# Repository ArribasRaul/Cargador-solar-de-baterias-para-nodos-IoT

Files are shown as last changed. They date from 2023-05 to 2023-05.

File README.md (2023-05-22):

# Cargador solar de baterias para nodos IoT

Diseño y desarrollo de un sistema que permita gestionar la energía generada por paneles solares de baja potencia de hasta 14 V y 3A . El sistema empleará una PCB que alimentará una batería de litio de 3,7V y una carga variable que consuma 3,3V o 5V y hasta 2A.
Proyecto de fin de grado realizado en la UPNa por Raúl Arribas Antón y supervisado por el Dr. Santiago Tainta Ausejo.

Universidad Publica de Navarra

##  [1. Códigos](https://github.com/ArribasRaul/Cargador-solar-de-baterias-para-nodos-IoT/tree/main/1.%20Codigos "Heading link")

Repositorio de los códigos utilizados durante el proyecto.

- Lectura_BQ25895

Codigo para la lectura de los registros del BQ25895 y escritura de estos en el monitor serie (Arduino Uno o Atmega328P)

- MPPT

Código para la implementación de un controlador MPPT (Arduino Uno o Atmega328P)
 
- Sistema_de_medida

Código y montaje para un sistema de medión de la eficiencia de un sistema de carga de baterias, basado en el INA3221, Arduino Uno y un modulo de microSD.

##  [2. PCB](https://github.com/ArribasRaul/Cargador-solar-de-baterias-para-nodos-IoT/tree/main/2.%20PCB "Heading link")

- Gerbers

Diseño de la PCB del cargador

- Lista de componentes de la PCB

Lista de los componentes usados en la PCB, sus referencias, cantidades y referencias de compra.

- Controlador

Comparación de los diferentes controladores de carga en el mercado.

- Regulador 3,3 V

Comparación de los diferentes convertidores DC/DC de 3,3 V en el mercado.

- Regulador 5 V

Comparación de los diferentes convertidores DC/DC de 5 V en el mercado.

##  [3. Pruebas PCB](https://github.com/ArribasRaul/Cargador-solar-de-baterias-para-nodos-IoT/tree/main/3.%20Pruebas%20PCB "Heading link")

- Lecturas

Datos en bruto conseguidos con el sistema de medida

- Comparación DFRobot y Desarollada

Comparación de funcionamiento de una PCB comercial (Solar Power Manager for 9V/12V/18V solar panel) de la marca DFRobot y la PCB desarrollada en diferentes situaciones de uso, conectadas a una fuente de alimentación.

- DFRobot

Funcionamiento de la placa de DFRobot con una alimentacion de dos paneles solares de baja potencia (9 V y 400 mA)

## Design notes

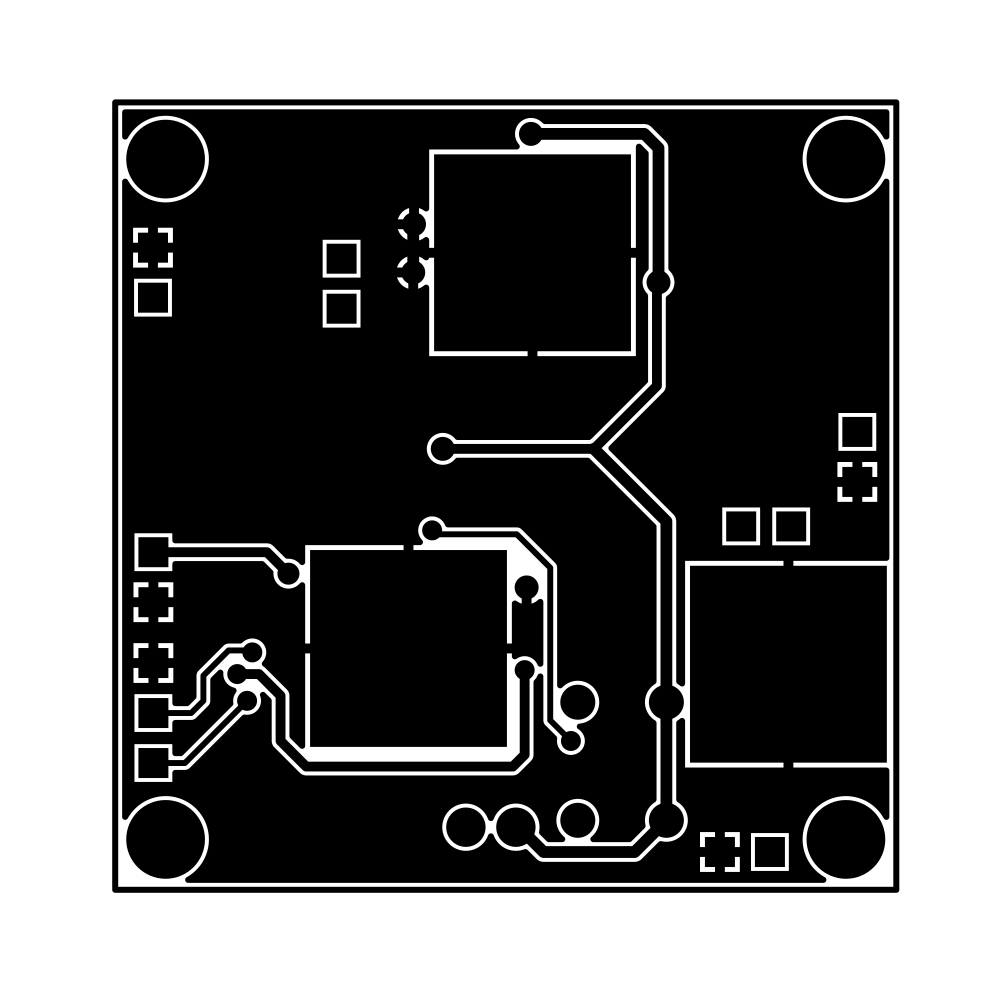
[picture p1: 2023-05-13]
2. PCB/Fotos PCB/4. Botton copper.png

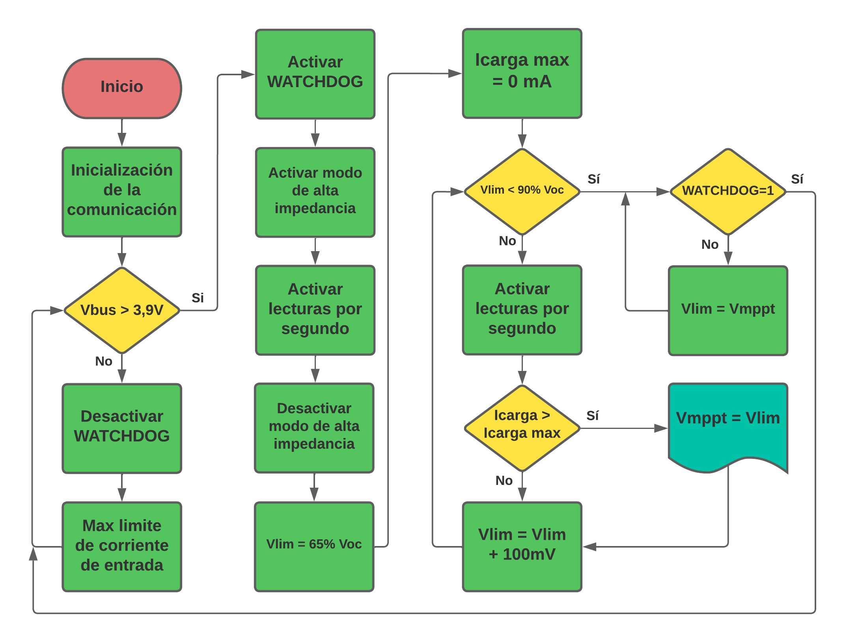
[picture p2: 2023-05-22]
1. Codigos/MPPT/Diagrama MPPT.png

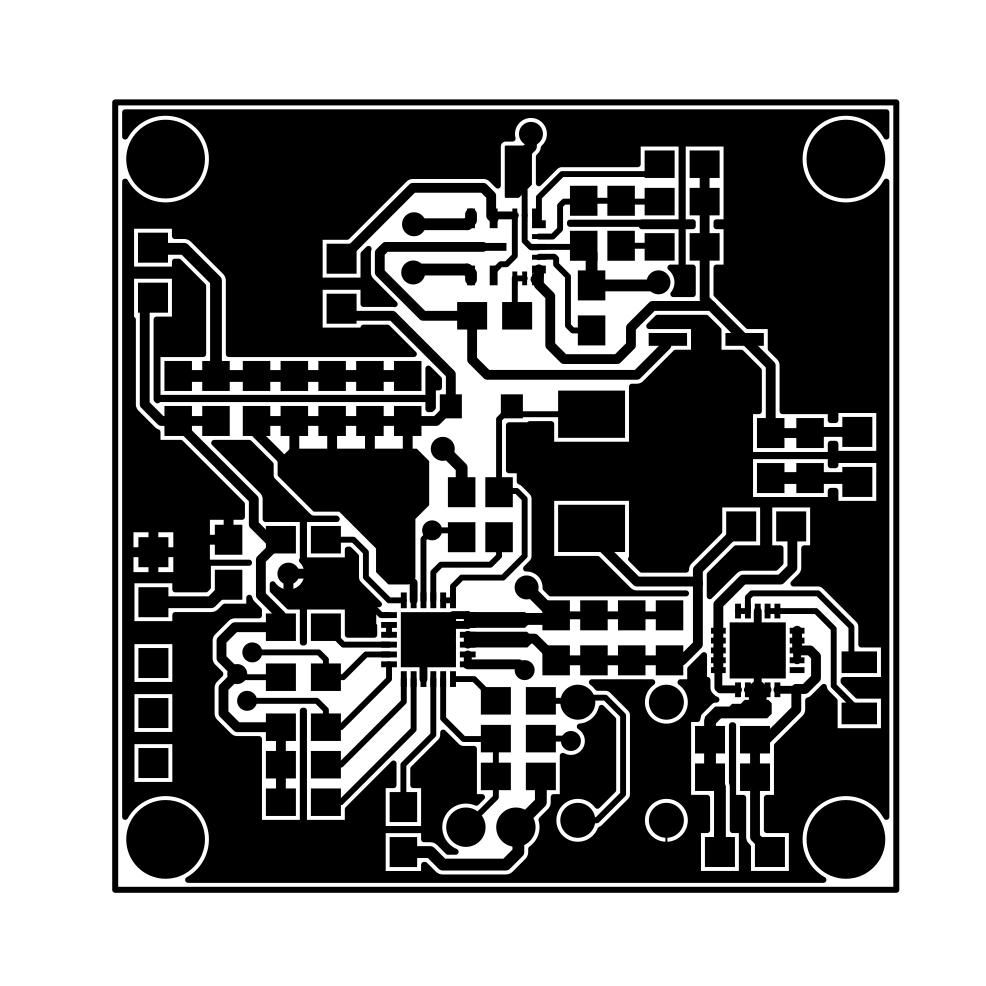
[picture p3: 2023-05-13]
2. PCB/Fotos PCB/3. Top copper.png

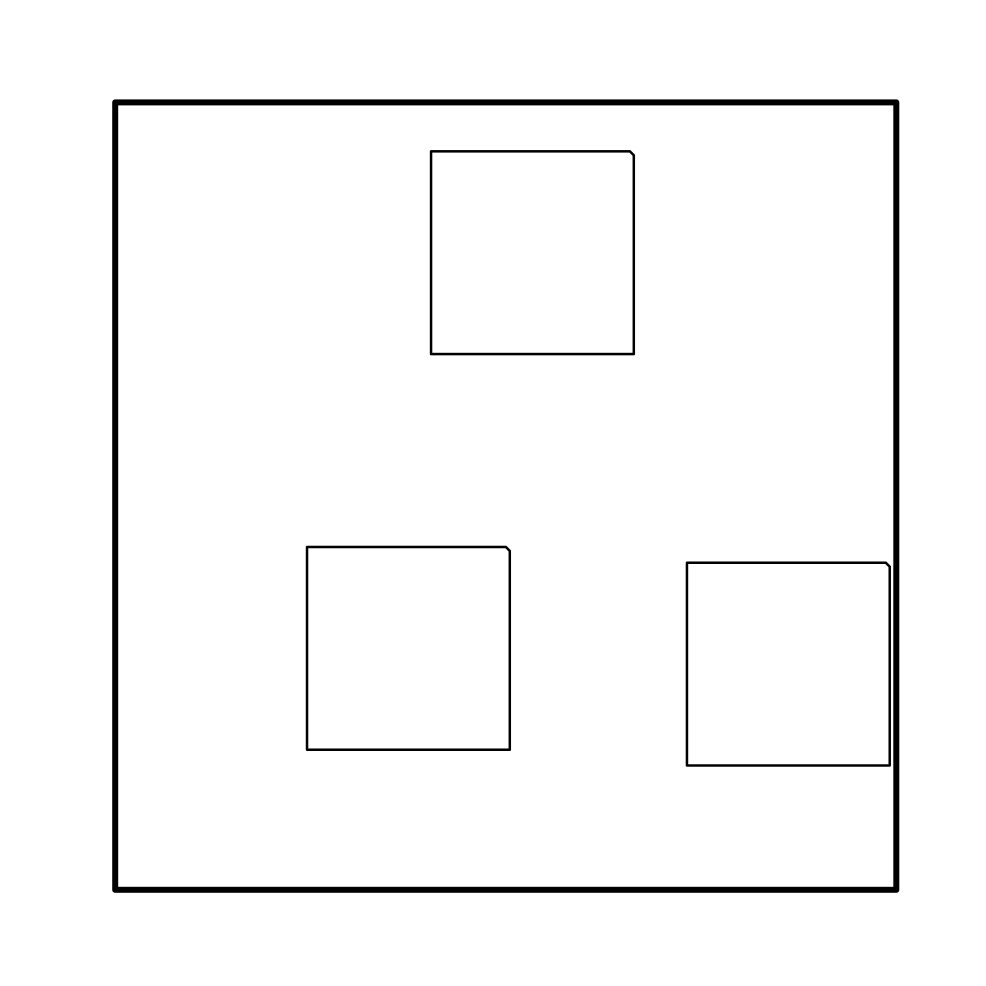
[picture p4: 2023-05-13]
2. PCB/Fotos PCB/6. Botton silckscreen.png

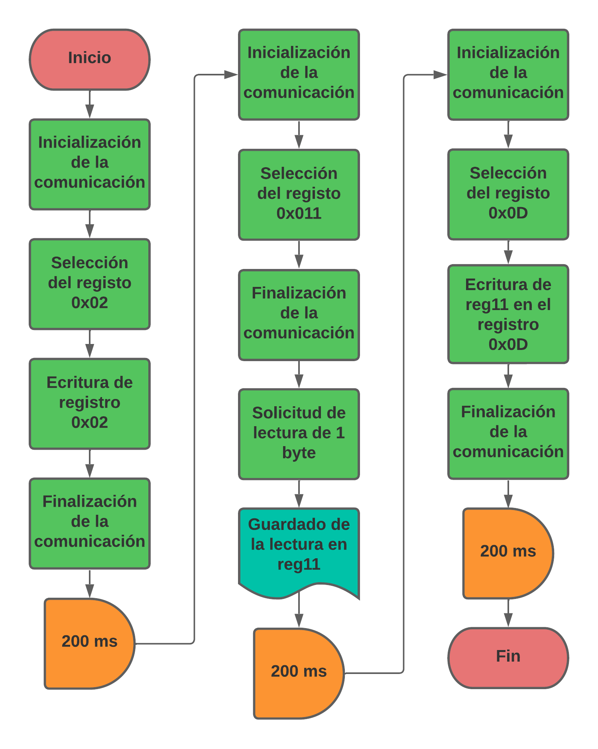
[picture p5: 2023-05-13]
1. Codigos/MPPT/Diagrama de flujo MPPT.png

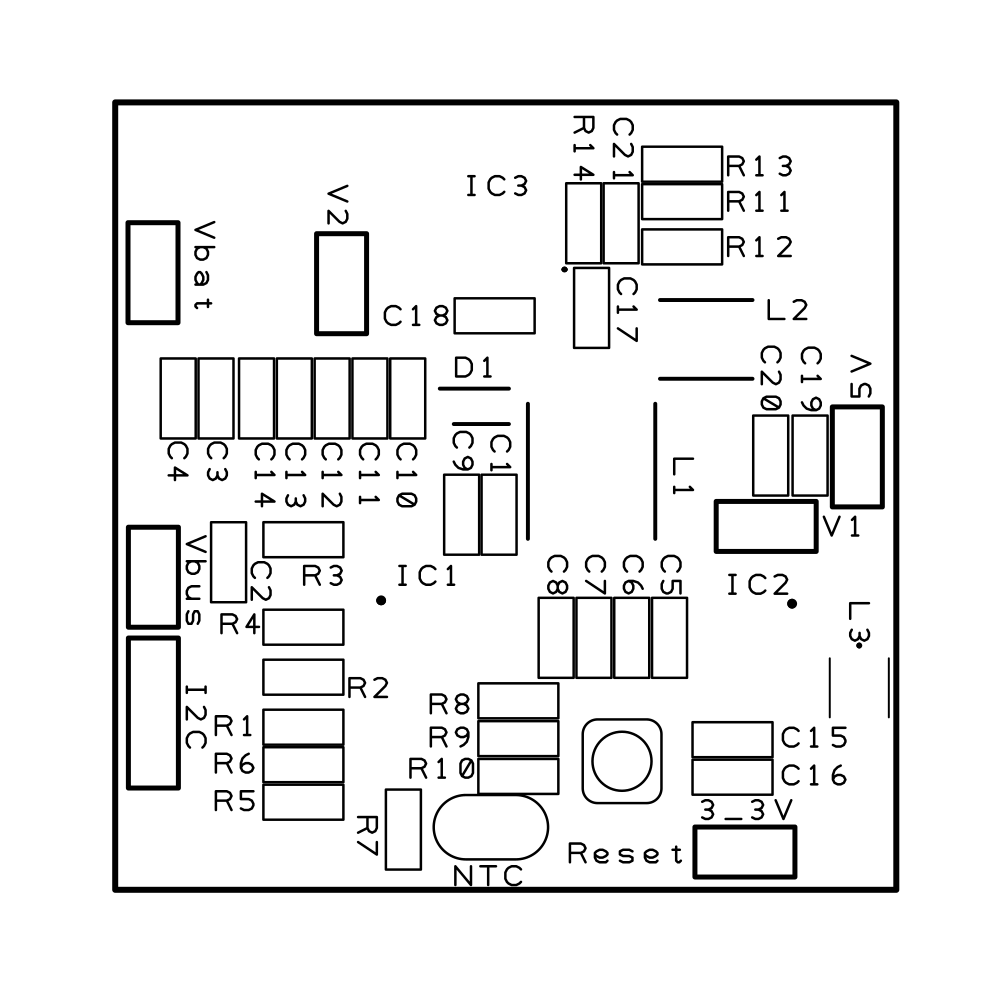
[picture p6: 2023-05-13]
2. PCB/Fotos PCB/1. Top silckscreen.png

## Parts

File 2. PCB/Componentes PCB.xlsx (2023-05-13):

Nombre | Cantidad | Valores | Decripción | Formato | Codigo RS | Mouser REF
R1/R2/R3/R4/R5/R6/R8 | 7 | 10k |  | 1206 | 788-3981 | 791-RMC1/8-1002FTP
R7 | 1 | 180 |  | 1206 | 721-9762 | 791-WR12X1800FTL
R9 | 1 | 5,23k |  | 1206 | - | 652-CR1206FX-5231ELF
R10 | 1 | 30,1k |  | 1206 | 243-0531 | 652-CR1206FX-3012ELF
R11/R13 | 2 | 100k |  | 1206 | 721-9986 | 603-RC1206JR-07100KL
R12 | 1 | 1k |  | 1206 | 721-9829 | 791-RMC1/8K1001FTP
R14 | 1 | 24,9k |  | 1206 | 252-7591 | 791-RMC1/8K2492FTP
C1 | 1 | 47n |  | 1206 | 250-7701 | 791-1206B473K500CT
C2/C17 | 2 | 1u |  | 1206 | 242-7428 | 187-CL31B105KBHNFNE
C3/C4/C5/C6/C7/C8/ C10/C11/C12/C13/C14 | 11 | 10u |  | 1206 | 260-8829 | 187-CL31A106MAHNNNE
C9 | 1 | 4,7u |  | 1206 | 247-8164 | 187-CL31B475KAHNNNE
C15/C16/C19/C20 | 4 | 22u |  | 1206 | 247-8160 | 187-CL31A226MOCLNNC
C18 | 1 | 100n |  | 1206 | 669-8417 | 791-SH21B104K160CT
C21 | 1 | 22p |  | 1206 | 669-8482 | 791-0805N220K201CT
D1 | 1 | 20V 1A | Diodo Schottky | SOD-123W | 151-3223 | 771-PMEG2010BER115
L1 | 1 | 2,2u |  | 2525 | - | 70-IHLP2525CZER2R2M1
L2 | 1 | 1,5u |  | - | - | 652-SRP4012TA-1R5M
L3 | 1 | 1u |  | - | - | 810-SPM3012T-1R0M
IC1 | 1 | - | BQ25895MRTWT | - | - | 595-BQ25895RTWR
IC2 | 1 | - | ISL91110IRNZ-T7A | - | - | 968-ISL91110IRNZ-T7A
IC3 | 1 | - | LMQ62440CPPQRJRRQ1 | - | - | 595-Q62440CPPQRJRRQ1
NTC | 1 | 10k | Termistores NTC, 10kΩ, 1% | - | 179-3836 | 954-103AT-2
Reset | 1 | - | Pushbutton | - | 479-1435 | 710-430172073816
V1/V2 | 2 | - | 2 Pines macho-macho | - | 251-8086 | 571-5-146274-2
I2C | 1 | - | 3 Pines macho-macho | - | 745-7068 | 571-5-146274-2
Vbat/Vbus/3_3V/5V | 4 | - | Conector, 2,54 mm | - | 790-1098 | 651-1725656

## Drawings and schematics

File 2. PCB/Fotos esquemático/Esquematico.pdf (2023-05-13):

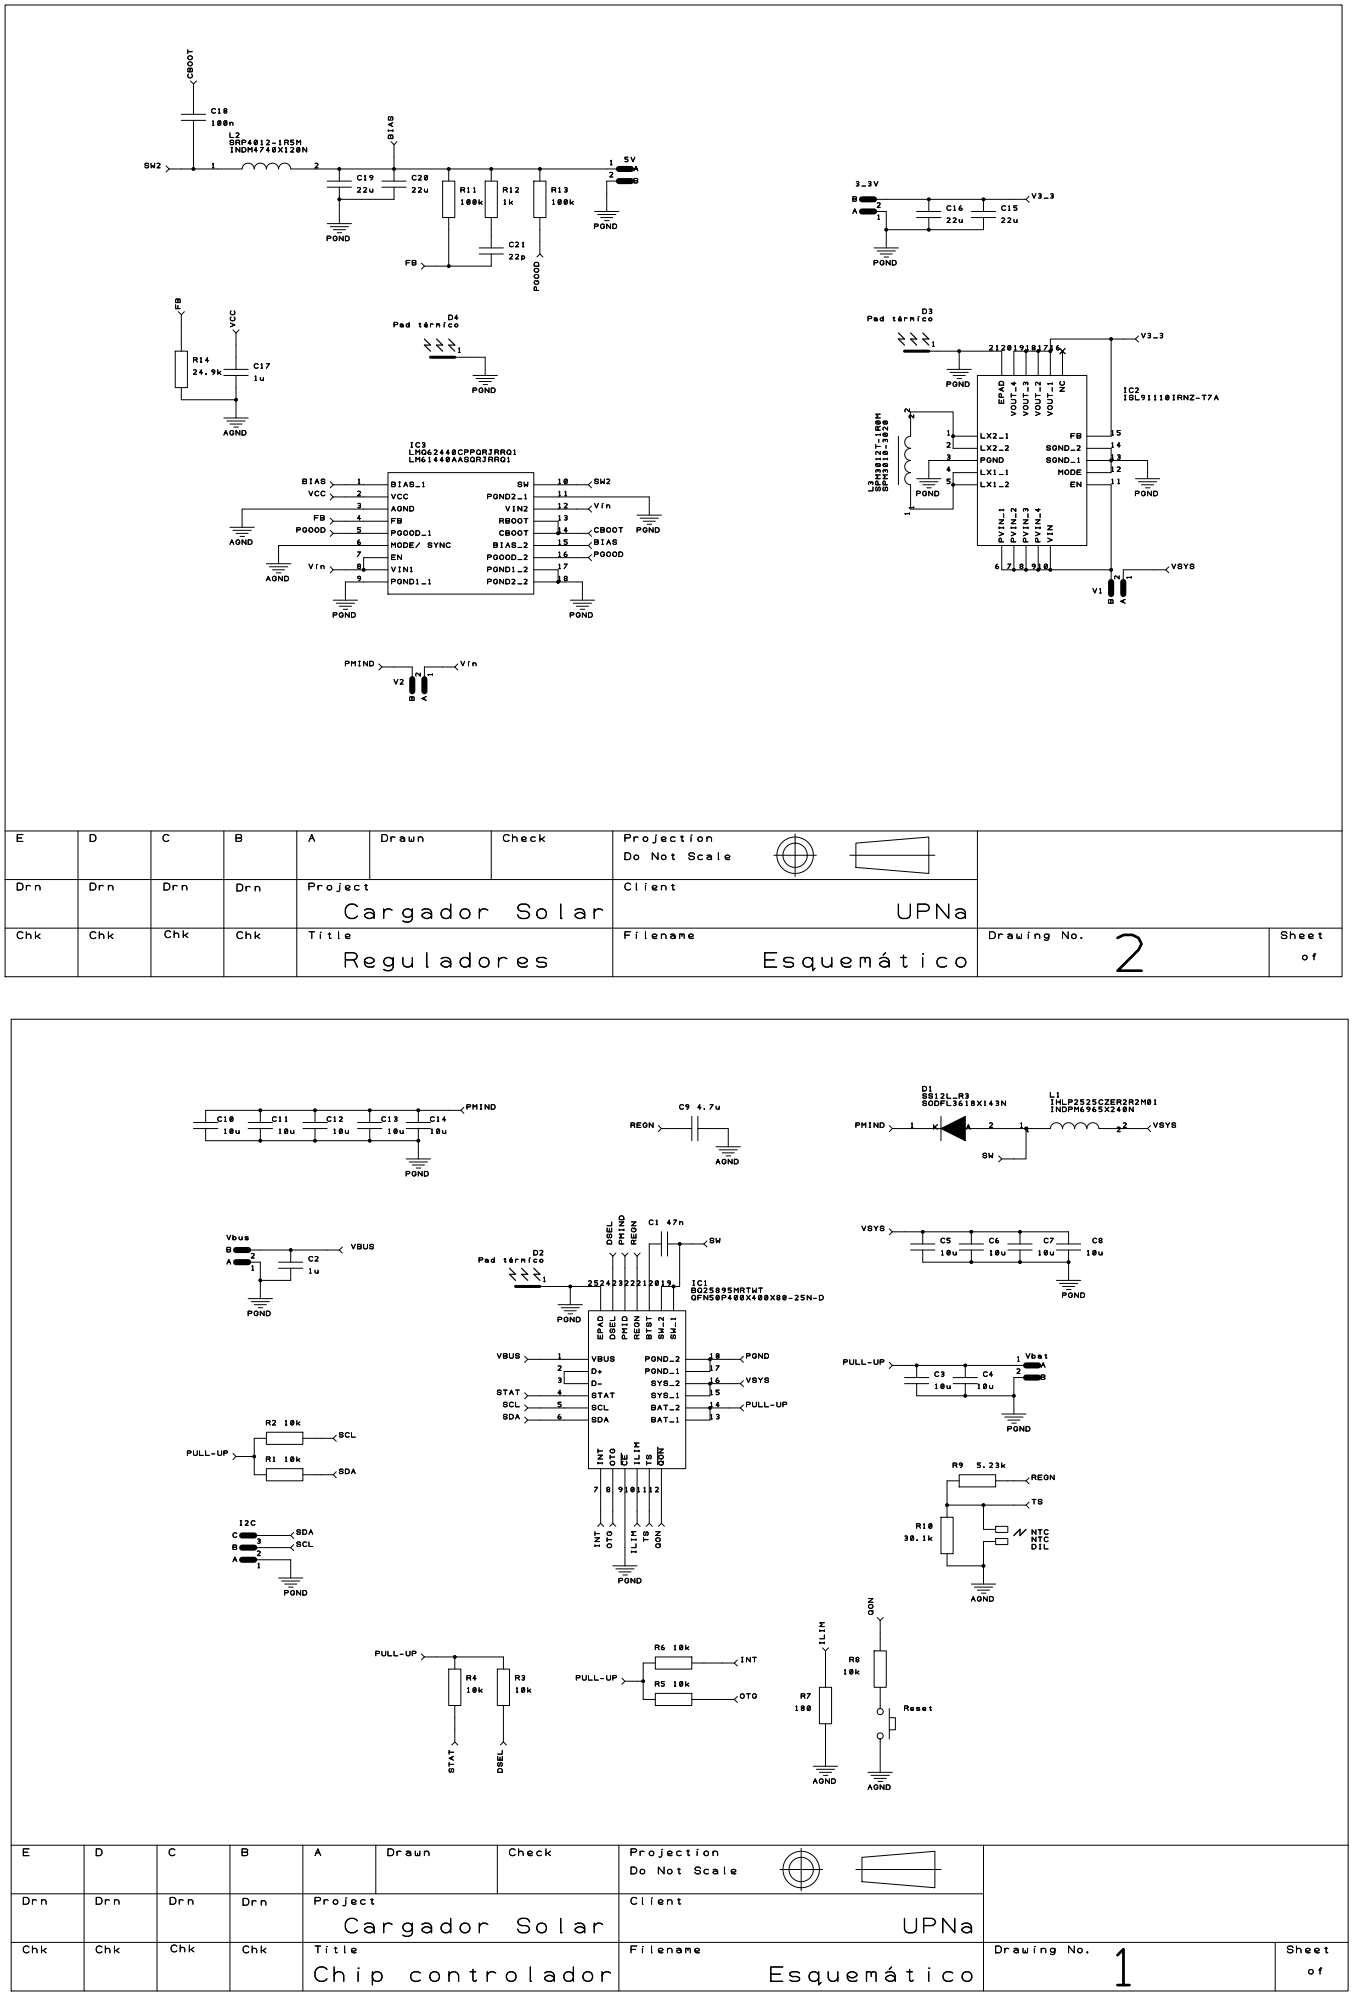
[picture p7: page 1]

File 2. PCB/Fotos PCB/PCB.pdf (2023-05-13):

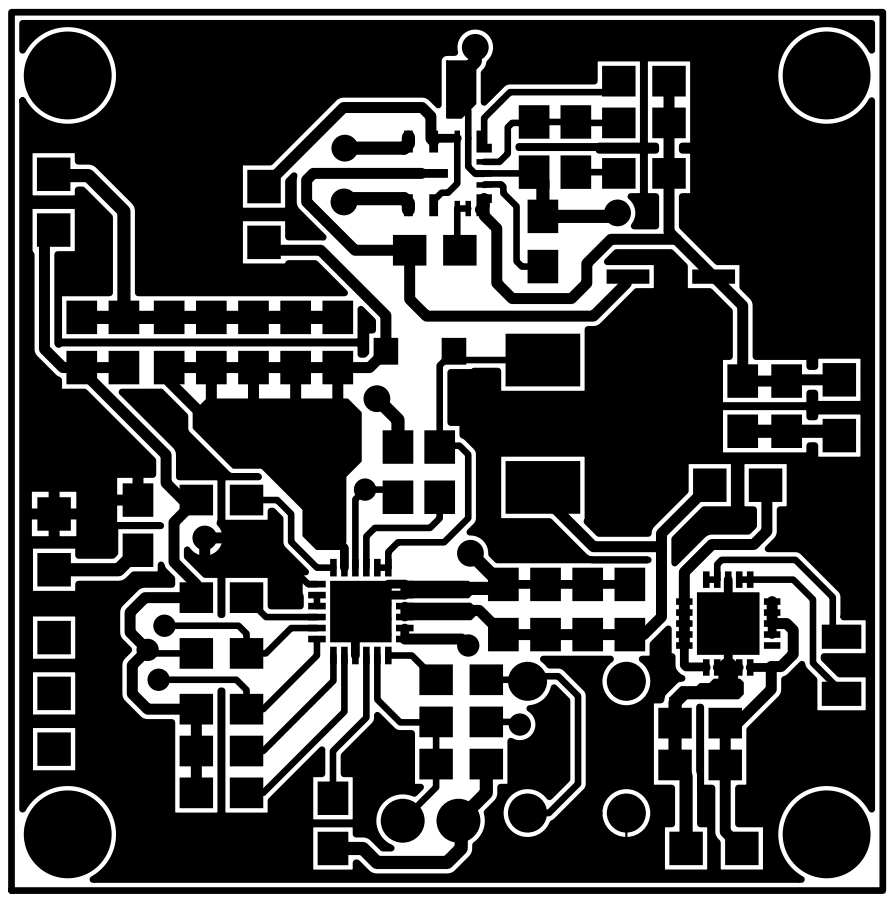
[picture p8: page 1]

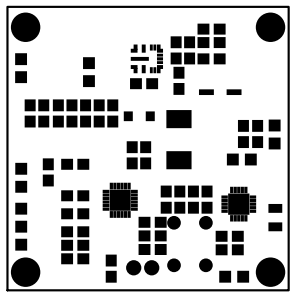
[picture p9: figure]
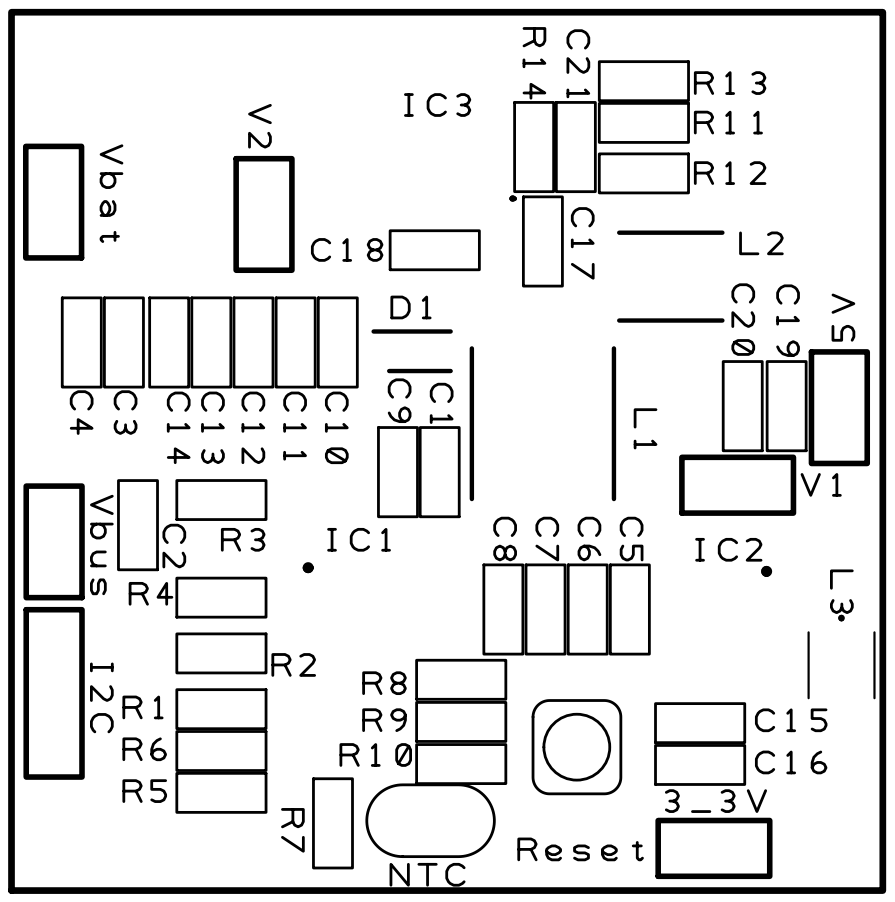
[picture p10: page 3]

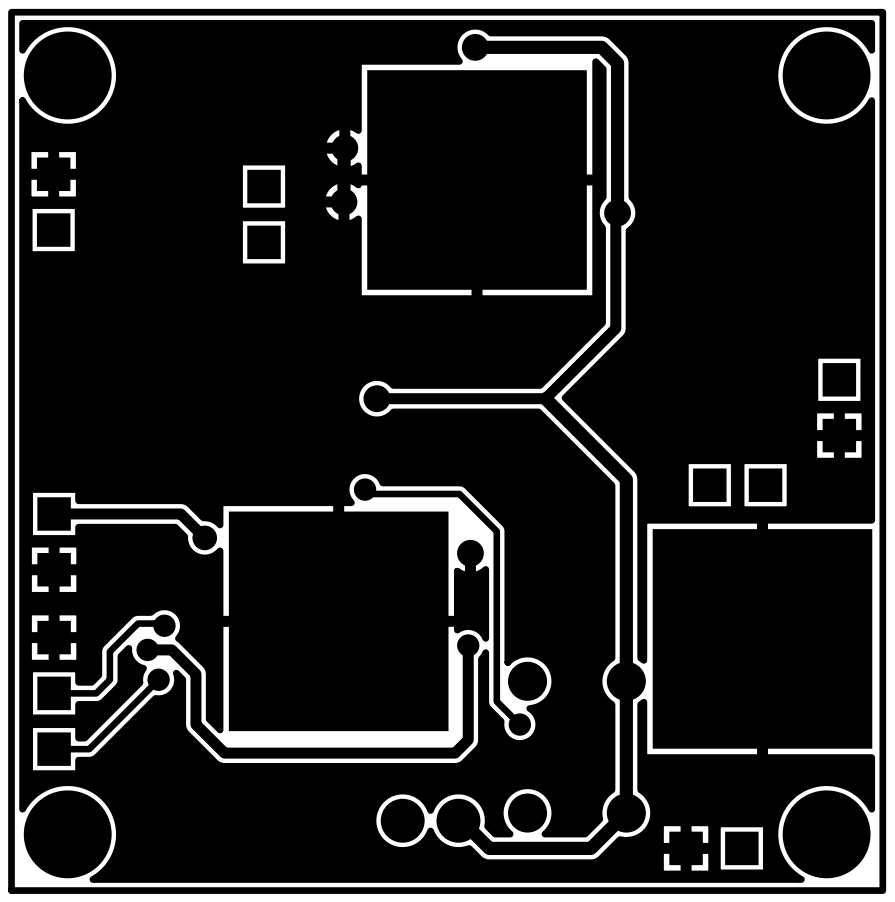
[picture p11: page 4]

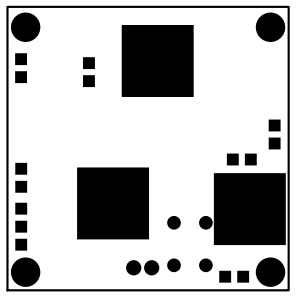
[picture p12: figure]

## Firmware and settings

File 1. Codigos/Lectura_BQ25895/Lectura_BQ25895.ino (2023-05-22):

////////Comunicación///////
#include <Wire.h>                 // Incluimos la librería para comunicarnos por I2C
#define DEVICE_I2C_ADDRESS 0x6A
byte reg0E;
byte reg0F;
byte reg11;
byte reg12;
byte reg14;
///////////////////////////

void setup(void) {
  Wire.begin();
//  Wire.beginTransmission(DEVICE_I2C_ADDRESS);
//  Wire.write(0x02);
//  Wire.write(0b01000000);
//  Wire.endTransmission();
  Serial.begin(9600);
  Serial.println("Arrancado");
}

void loop() {
  Serial.println("Escritura registro");
  Wire.begin();
  Wire.beginTransmission(DEVICE_I2C_ADDRESS);
  Wire.write(0x02);
  Wire.write(0b10111101);
  Wire.endTransmission();
  delay(100);
 /* 
  Serial.println("Escritura registro");
  Wire.begin();
  Wire.beginTransmission(DEVICE_I2C_ADDRESS);
  Wire.write(0x09);
  Wire.write(0b01000100);
  Wire.endTransmission();
  delay(100);

  Serial.println("Escritura registro");
  Wire.begin();
  Wire.beginTransmission(DEVICE_I2C_ADDRESS);
  Wire.write(0x04);
  Wire.write(0b00010000);
  Wire.endTransmission();
  delay(100);
  
  Serial.println("Escritura registro");
  Wire.begin();
  Wire.beginTransmission(DEVICE_I2C_ADDRESS);
  Wire.write(0x03);
  Wire.write(0b00011010);
  Wire.endTransmission();
  delay(100);

  Serial.println("Escritura registro");
  Wire.begin();
  Wire.beginTransmission(DEVICE_I2C_ADDRESS);
  Wire.write(0x07);
  Wire.write(0b10001100);
  Wire.endTransmission();
  delay(100); */
  
  Wire.beginTransmission(DEVICE_I2C_ADDRESS);
  Wire.write(0x00);
  Wire.endTransmission();
  Serial.print("Read REG 0x00: ");
  Wire.requestFrom(DEVICE_I2C_ADDRESS, 1);
  reg14 = Wire.read();

  int x7 = bitRead(reg14, 7);
  Serial.print(x7);
  Serial.print(" ");

  int x6 = bitRead(reg14, 6);
  Serial.print(x6);
  Serial.print(" ");

  int x5 = bitRead(reg14, 5);
  Serial.print(x5);
  Serial.print(" ");

  int x4 = bitRead(reg14, 4);
  Serial.print(x4);
  Serial.print(" ");

  int x3 = bitRead(reg14, 3);
  Serial.print(x3);
  Serial.print(" ");

  int x2 = bitRead(reg14, 2);
  Serial.print(x2);
  Serial.print(" ");

  int x1 = bitRead(reg14, 1);
  Serial.print(x1);
  Serial.print(" ");

  int x0 = bitRead(reg14, 0);
  Serial.print(x0);
  Serial.println(" ");

  delay(200);

  Wire.beginTransmission(DEVICE_I2C_ADDRESS);
  Wire.write(0x01);
  Wire.endTransmission();
  Serial.print("Read REG 0x01: ");
  Wire.requestFrom(DEVICE_I2C_ADDRESS, 1);
  reg14 = Wire.read();


  int x8 = bitRead(reg14, 7);
  Serial.print(x8);
  Serial.print(" ");

  int x9 = bitRead(reg14, 6);
  Serial.print(x9);
  Serial.print(" ");

  int x10 = bitRead(reg14, 5);
  Serial.print(x10);
  Serial.print(" ");

  int x11 = bitRead(reg14, 4);
  Serial.print(x11);
  Serial.print(" ");

  int x12 = bitRead(reg14, 3);
  Serial.print(x12);
  Serial.print(" ");

  int x13 = bitRead(reg14, 2);
  Serial.print(x13);
  Serial.print(" ");

  int x14 = bitRead(reg14, 1);
  Serial.print(x14);
  Serial.print(" ");

  int x15 = bitRead(reg14, 0);
  Serial.print(x15);
  Serial.println(" ");
  
  delay(200);

  Wire.beginTransmission(DEVICE_I2C_ADDRESS);
  Wire.write(0x02);
  Wire.endTransmission();
  Serial.print("Read REG 0x02: ");
  Wire.requestFrom(DEVICE_I2C_ADDRESS, 1);
  reg14 = Wire.read();


  int x16 = bitRead(reg14, 7);
  Serial.print(x16);
  Serial.print(" ");

  int x17 = bitRead(reg14, 6);
  Serial.print(x17);
  Serial.print(" ");

  int x18 = bitRead(reg14, 5);
  Serial.print(x18);
  Serial.print(" ");

  int x19 = bitRead(reg14, 4);
  Serial.print(x19);
  Serial.print(" ");

  int x20 = bitRead(reg14, 3);
  Serial.print(x20);
  Serial.print(" ");

  int x21 = bitRead(reg14, 2);
  Serial.print(x21);
  Serial.print(" ");

  int x22 = bitRead(reg14, 1);
  Serial.print(x22);
  Serial.print(" ");

  int x23 = bitRead(reg14, 0);
  Serial.print(x23);
  Serial.println(" ");
  
  delay(200);

  Wire.beginTransmission(DEVICE_I2C_ADDRESS);
  Wire.write(0x03);
  Wire.endTransmission();
  Serial.print("Read REG 0x03: ");
  Wire.requestFrom(DEVICE_I2C_ADDRESS, 1);
  reg14 = Wire.read();


  int x24 = bitRead(reg14, 7);
  Serial.print(x24);
  Serial.print(" ");

  int x25 = bitRead(reg14, 6);
  Serial.print(x25);
  Serial.print(" ");

  int x26 = bitRead(reg14, 5);
  Serial.print(x26);
  Serial.print(" ");

  int x27 = bitRead(reg14, 4);
  Serial.print(x27);
  Serial.print(" ");

  int x28 = bitRead(reg14, 3);
  Serial.print(x28);
  Serial.print(" ");

  int x29 = bitRead(reg14, 2);
  Serial.print(x29);
  Serial.print(" ");

  int x30 = bitRead(reg14, 1);
  Serial.print(x30);
  Serial.print(" ");

  int x31 = bitRead(reg14, 0);
  Serial.print(x31);
  Serial.println(" ");
  
  delay(200);

  Wire.beginTransmission(DEVICE_I2C_ADDRESS);
  Wire.write(0x04);
  Wire.endTransmission();
  Serial.print("Read REG 0x04: ");
  Wire.requestFrom(DEVICE_I2C_ADDRESS, 1);
  reg14 = Wire.read();


  int x32 = bitRead(reg14, 7);
  Serial.print(x32);
  Serial.print(" ");

  int x33 = bitRead(reg14, 6);
  Serial.print(x33);
  Serial.print(" ");

  int x34 = bitRead(reg14, 5);
  Serial.print(x34);
  Serial.print(" ");

  int x35 = bitRead(reg14, 4);
  Serial.print(x35);
  Serial.print(" ");

  int x36 = bitRead(reg14, 3);
  Serial.print(x36);
  Serial.print(" ");

  int x37 = bitRead(reg14, 2);
  Serial.print(x37);
  Serial.print(" ");

  int x38 = bitRead(reg14, 1);
  Serial.print(x38);
  Serial.print(" ");

  int x39 = bitRead(reg14, 0);
  Serial.print(x39);
  Serial.println(" ");
  
  delay(200);

  Wire.beginTransmission(DEVICE_I2C_ADDRESS);
  Wire.write(0x05);
  Wire.endTransmission();
  Serial.print("Read REG 0x05: ");
  Wire.requestFrom(DEVICE_I2C_ADDRESS, 1);
  reg14 = Wire.read();


  int x40 = bitRead(reg14, 7);
  Serial.print(x40);
  Serial.print(" ");

  int x41 = bitRead(reg14, 6);
  Serial.print(x41);
  Serial.print(" ");

  int x42 = bitRead(reg14, 5);
  Serial.print(x42);
  Serial.print(" ");

  int x43 = bitRead(reg14, 4);
  Serial.print(x43);
  Serial.print(" ");

  int x44 = bitRead(reg14, 3);
  Serial.print(x44);
  Serial.print(" ");

  int x45 = bitRead(reg14, 2);
  Serial.print(x45);
  Serial.print(" ");

  int x46 = bitRead(reg14, 1);
  Serial.print(x46);
  Serial.print(" ");

  int x47 = bitRead(reg14, 0);
  Serial.print(x47);
  Serial.println(" ");
  
  delay(200);

  Wire.beginTransmission(DEVICE_I2C_ADDRESS);
  Wire.write(0x06);
  Wire.endTransmission();
  Serial.print("Read REG 0x06: ");
  Wire.requestFrom(DEVICE_I2C_ADDRESS, 1);
  reg14 = Wire.read();


  int x48 = bitRead(reg14, 7);
  Serial.print(x48);
  Serial.print(" ");

  int x49 = bitRead(reg14, 6);
  Serial.print(x49);
  Serial.print(" ");

  int x50 = bitRead(reg14, 5);
  Serial.print(x50);
  Serial.print(" ");

  int x51 = bitRead(reg14, 4);
  Serial.print(x51);
  Serial.print(" ");

  int x52 = bitRead(reg14, 3);
  Serial.print(x52);
  Serial.print(" ");

  int x53 = bitRead(reg14, 2);
  Serial.print(x53);
  Serial.print(" ");

  int x54 = bitRead(reg14, 1);
  Serial.print(x54);
  Serial.print(" ");

  int x55 = bitRead(reg14, 0);
  Serial.print(x55);
  Serial.println(" ");
  
  delay(200);

  Wire.beginTransmission(DEVICE_I2C_ADDRESS);
  Wire.write(0x07);
  Wire.endTransmission();
  Serial.print("Read REG 0x07: ");
  Wire.requestFrom(DEVICE_I2C_ADDRESS, 1);
  reg14 = Wire.read();


  int x56 = bitRead(reg14, 7);
  Serial.print(x56);
  Serial.print(" ");

  int x57 = bitRead(reg14, 6);
  Serial.print(x57);
  Serial.print(" ");

  int x58 = bitRead(reg14, 5);
  Serial.print(x58);
  Serial.print(" ");

  int x59 = bitRead(reg14, 4);
  Serial.print(x59);
  Serial.print(" ");

  int x60 = bitRead(reg14, 3);
  Serial.print(x60);
  Serial.print(" ");

  int x61 = bitRead(reg14, 2);
  Serial.print(x61);
  Serial.print(" ");

  int x62 = bitRead(reg14, 1);
  Serial.print(x62);
  Serial.print(" ");

  int x63 = bitRead(reg14, 0);
  Serial.print(x63);
  Serial.println(" ");
  
  delay(200);

  Wire.beginTransmission(DEVICE_I2C_ADDRESS);
  Wire.write(0x08);
  Wire.endTransmission();
  Serial.print("Read REG 0x08: ");
  Wire.requestFrom(DEVICE_I2C_ADDRESS, 1);
  reg14 = Wire.read();


  int x64 = bitRead(reg14, 7);
  Serial.print(x64);
  Serial.print(" ");

  int x65 = bitRead(reg14, 6);
  Serial.print(x65);
  Serial.print(" ");

  int x66 = bitRead(reg14, 5);
  Serial.print(x66);
  Serial.print(" ");

  int x67 = bitRead(reg14, 4);
  Serial.print(x67);
  Serial.print(" ");

  int x68 = bitRead(reg14, 3);
  Serial.print(x68);
  Serial.print(" ");

  int x69 = bitRead(reg14, 2);
  Serial.print(x69);
  Serial.print(" ");

  int x70 = bitRead(reg14, 1);
  Serial.print(x70);
  Serial.print(" ");

  int x71 = bitRead(reg14, 0);
  Serial.print(x71);
  Serial.println(" ");
  
  delay(200);

  Wire.beginTransmission(DEVICE_I2C_ADDRESS);
  Wire.write(0x09);
  Wire.endTransmission();
  Serial.print("Read REG 0x09: ");
  Wire.requestFrom(DEVICE_I2C_ADDRESS, 1);
  reg14 = Wire.read();


  int x72 = bitRead(reg14, 7);
  Serial.print(x72);
  Serial.print(" ");

  int x73 = bitRead(reg14, 6);
  Serial.print(x73);
  Serial.print(" ");

  int x74 = bitRead(reg14, 5);
  Serial.print(x74);
  Serial.print(" ");

  int x75 = bitRead(reg14, 4);
  Serial.print(x75);
  Serial.print(" ");

  int x76 = bitRead(reg14, 3);
  Serial.print(x76);
  Serial.print(" ");

  int x77 = bitRead(reg14, 2);
  Serial.print(x77);
  Serial.print(" ");

  int x78 = bitRead(reg14, 1);
  Serial.print(x78);
  Serial.print(" ");

  int x79 = bitRead(reg14, 0);
  Serial.print(x79);
  Serial.println(" ");
  
  delay(200);

  Wire.beginTransmission(DEVICE_I2C_ADDRESS);
  Wire.write(0x0A);
  Wire.endTransmission();
  Serial.print("Read REG 0x0A: ");
  Wire.requestFrom(DEVICE_I2C_ADDRESS, 1);
  reg14 = Wire.read();


  int x80 = bitRead(reg14, 7);
  Serial.print(x80);
  Serial.print(" ");

  int x81 = bitRead(reg14, 6);
  Serial.print(x81);
  Serial.print(" ");

  int x82 = bitRead(reg14, 5);
  Serial.print(x82);
  Serial.print(" ");

  int x83 = bitRead(reg14, 4);
  Serial.print(x83);
  Serial.print(" ");

  int x84 = bitRead(reg14, 3);
  Serial.print(x84);
  Serial.print(" ");

  int x85 = bitRead(reg14, 2);
  Serial.print(x85);
  Serial.print(" ");

  int x86 = bitRead(reg14, 1);
  Serial.print(x86);
  Serial.print(" ");

  int x87 = bitRead(reg14, 0);
  Serial.print(x87);
  Serial.println(" ");
  
  delay(200);

  Wire.beginTransmission(DEVICE_I2C_ADDRESS);
  Wire.write(0x0B);
  Wire.endTransmission();
  Serial.print("Read REG 0x0B: ");
  Wire.requestFrom(DEVICE_I2C_ADDRESS, 1);
  reg14 = Wire.read();


  int x88 = bitRead(reg14, 7);
  Serial.print(x88);
  Serial.print(" ");

  int x89 = bitRead(reg14, 6);
  Serial.print(x89);
  Serial.print(" ");

  int x90 = bitRead(reg14, 5);
  Serial.print(x90);
  Serial.print(" ");

  int x91 = bitRead(reg14, 4);
  Serial.print(x91);
  Serial.print(" ");

  int x92 = bitRead(reg14, 3);
  Serial.print(x92);
  Serial.print(" ");

  int x93 = bitRead(reg14, 2);
  Serial.print(x93);
  Serial.print(" ");

  int x94 = bitRead(reg14, 1);
  Serial.print(x94);
  Serial.print(" ");

  int x95 = bitRead(reg14, 0);
  Serial.print(x95);
  Serial.println(" ");
  
  delay(200);

  Wire.beginTransmission(DEVICE_I2C_ADDRESS);
  Wire.write(0x0C);
  Wire.endTransmission();
  Serial.print("Read REG 0x0C: ");
  Wire.requestFrom(DEVICE_I2C_ADDRESS, 1);
  reg14 = Wire.read();


  int x96 = bitRead(reg14, 7);
  Serial.print(x96);
  Serial.print(" ");

  int x97 = bitRead(reg14, 6);
  Serial.print(x97);
  Serial.print(" ");

  int x98 = bitRead(reg14, 5);
  Serial.print(x98);
  Serial.print(" ");

  int x99 = bitRead(reg14, 4);
  Serial.print(x99);
  Serial.print(" ");

  int x100 = bitRead(reg14, 3);
  Serial.print(x100);
  Serial.print(" ");

  int x101 = bitRead(reg14, 2);
  Serial.print(x101);
  Serial.print(" ");

  int x102 = bitRead(reg14, 1);
  Serial.print(x102);
  Serial.print(" ");

  int x103 = bitRead(reg14, 0);
  Serial.print(x103);
  Serial.println(" ");
  
  delay(200);

  Wire.beginTransmission(DEVICE_I2C_ADDRESS);
  Wire.write(0x0D);
  Wire.endTransmission();
  Serial.print("Read REG 0x0D: ");
  Wire.requestFrom(DEVICE_I2C_ADDRESS, 1);
  reg14 = Wire.read();


  int x104 = bitRead(reg14, 7);
  Serial.print(x104);
  Serial.print(" ");

  int x105 = bitRead(reg14, 6);
  Serial.print(x105);
  Serial.print(" ");

  int x106 = bitRead(reg14, 5);
  Serial.print(x106);
  Serial.print(" ");

  int x107 = bitRead(reg14, 4);
  Serial.print(x107);
  Serial.print(" ");

  int x108 = bitRead(reg14, 3);
  Serial.print(x108);
  Serial.print(" ");

  int x109 = bitRead(reg14, 2);
  Serial.print(x109);
  Serial.print(" ");

  int x110 = bitRead(reg14, 1);
  Serial.print(x110);
  Serial.print(" ");

  int x111 = bitRead(reg14, 0);
  Serial.print(x111);
  Serial.println(" ");
  
  delay(200);

  Wire.beginTransmission(DEVICE_I2C_ADDRESS);
  Wire.write(0x0E);
  Wire.endTransmission();
  Serial.print("Read REG 0x0E: ");
  Wire.requestFrom(DEVICE_I2C_ADDRESS, 1);
  reg14 = Wire.read();


  int x112 = bitRead(reg14, 7);
  Serial.print(x112);
  Serial.print(" ");

  int x113 = bitRead(reg14, 6);
  Serial.print(x113);
  Serial.print(" ");

  int x114 = bitRead(reg14, 5);
  Serial.print(x114);
  Serial.print(" ");

  int x115 = bitRead(reg14, 4);
  Serial.print(x115);
  Serial.print(" ");

  int x116 = bitRead(reg14, 3);
  Serial.print(x116);
  Serial.print(" ");

  int x117 = bitRead(reg14, 2);
  Serial.print(x117);
  Serial.print(" ");

  int x118 = bitRead(reg14, 1);
  Serial.print(x118);
  Serial.print(" ");

  int x119 = bitRead(reg14, 0);
  Serial.print(x119);
  Serial.println(" ");
  
  delay(200);

  Wire.beginTransmission(DEVICE_I2C_ADDRESS);
  Wire.write(0x0F);
  Wire.endTransmission();
  Serial.print("Read REG 0x0F: ");
  Wire.requestFrom(DEVICE_I2C_ADDRESS, 1);
  reg14 = Wire.read();


  int x120 = bitRead(reg14, 7);
  Serial.print(x120);
  Serial.print(" ");

  int x121 = bitRead(reg14, 6);
  Serial.print(x121);
  Serial.print(" ");

  int x122 = bitRead(reg14, 5);
  Serial.print(x122);
  Serial.print(" ");

  int x123 = bitRead(reg14, 4);
  Serial.print(x123);
  Serial.print(" ");

  int x124 = bitRead(reg14, 3);
  Serial.print(x124);
  Serial.print(" ");

  int x125 = bitRead(reg14, 2);
  Serial.print(x125);
  Serial.print(" ");

  int x126 = bitRead(reg14, 1);
  Serial.print(x126);
  Serial.print(" ");

  int x127 = bitRead(reg14, 0);
  Serial.print(x127);
  Serial.println(" ");
  
  delay(200);

  Wire.beginTransmission(DEVICE_I2C_ADDRESS);
  Wire.write(0x10);
  Wire.endTransmission();
  Serial.print("Read REG 0x10: ");
  Wire.requestFrom(DEVICE_I2C_ADDRESS, 1);
  reg14 = Wire.read();


  int x128 = bitRead(reg14, 7);
  Serial.print(x128);
  Serial.print(" ");

  int x129 = bitRead(reg14, 6);
  Serial.print(x129);
  Serial.print(" ");

  int x130 = bitRead(reg14, 5);
  Serial.print(x130);
  Serial.print(" ");

  int x131 = bitRead(reg14, 4);
  Serial.print(x131);
  Serial.print(" ");

  int x132 = bitRead(reg14, 3);
  Serial.print(x132);
  Serial.print(" ");

  int x133 = bitRead(reg14, 2);
  Serial.print(x133);
  Serial.print(" ");

  int x134 = bitRead(reg14, 1);
  Serial.print(x134);
  Serial.print(" ");

  int x135 = bitRead(reg14, 0);
  Serial.print(x135);
  Serial.println(" ");
  
  delay(200);

  Wire.beginTransmission(DEVICE_I2C_ADDRESS);
  Wire.write(0x11);
  Wire.endTransmission();
  Serial.print("Read REG 0x11: ");
  Wire.requestFrom(DEVICE_I2C_ADDRESS, 1);
  reg14 = Wire.read();


  int x136 = bitRead(reg14, 7);
  Serial.print(x136);
  Serial.print(" ");

  int x137 = bitRead(reg14, 6);
  Serial.print(x137);
  Serial.print(" ");

  int x138 = bitRead(reg14, 5);
  Serial.print(x138);
  Serial.print(" ");

  int x139 = bitRead(reg14, 4);
  Serial.print(x139);
  Serial.print(" ");

  int x140 = bitRead(reg14, 3);
  Serial.print(x140);
  Serial.print(" ");

  int x141 = bitRead(reg14, 2);
  Serial.print(x141);
  Serial.print(" ");

  int x142 = bitRead(reg14, 1);
  Serial.print(x142);
  Serial.print(" ");

  int x143 = bitRead(reg14, 0);
  Serial.print(x143);
  Serial.println(" ");
  
  delay(200);

  Wire.beginTransmission(DEVICE_I2C_ADDRESS);
  Wire.write(0x12);
  Wire.endTransmission();
  Serial.print("Read REG 0x12: ");
  Wire.requestFrom(DEVICE_I2C_ADDRESS, 1);
  reg14 = Wire.read();


  int x144 = bitRead(reg14, 7);
  Serial.print(x144);
  Serial.print(" ");

  int x145 = bitRead(reg14, 6);
  Serial.print(x145);
  Serial.print(" ");

  int x146 = bitRead(reg14, 5);
  Serial.print(x146);
  Serial.print(" ");

  int x147 = bitRead(reg14, 4);
  Serial.print(x147);
  Serial.print(" ");

  int x148 = bitRead(reg14, 3);
  Serial.print(x148);
  Serial.print(" ");

  int x149 = bitRead(reg14, 2);
  Serial.print(x149);
  Serial.print(" ");

  int x150 = bitRead(reg14, 1);
  Serial.print(x150);
  Serial.print(" ");

  int x151 = bitRead(reg14, 0);
  Serial.print(x151);
  Serial.println(" ");
  
  delay(200);

  Wire.beginTransmission(DEVICE_I2C_ADDRESS);
  Wire.write(0x13);
  Wire.endTransmission();
  Serial.print("Read REG 0x13: ");
  Wire.requestFrom(DEVICE_I2C_ADDRESS, 1);
  reg14 = Wire.read();


  int x152 = bitRead(reg14, 7);
  Serial.print(x152);
  Serial.print(" ");

  int x153 = bitRead(reg14, 6);
  Serial.print(x153);
  Serial.print(" ");

  int x154 = bitRead(reg14, 5);
  Serial.print(x154);
  Serial.print(" ");

  int x155 = bitRead(reg14, 4);
  Serial.print(x155);
  Serial.print(" ");

  int x156 = bitRead(reg14, 3);
  Serial.print(x156);
  Serial.print(" ");

  int x157 = bitRead(reg14, 2);
  Serial.print(x157);
  Serial.print(" ");

  int x158 = bitRead(reg14, 1);
  Serial.print(x158);
  Serial.print(" ");

  int x159 = bitRead(reg14, 0);
  Serial.print(x159);
  Serial.println(" ");
  
  delay(200);

  Wire.beginTransmission(DEVICE_I2C_ADDRESS);
  Wire.write(0x14);
  Wire.endTransmission();
  Serial.print("Read REG 0x14: ");
  Wire.requestFrom(DEVICE_I2C_ADDRESS, 1);
  reg14 = Wire.read();


  int x160 = bitRead(reg14, 7);
  Serial.print(x160);
  Serial.print(" ");

  int x161 = bitRead(reg14, 6);
  Serial.print(x161);
  Serial.print(" ");

  int x162 = bitRead(reg14, 5);
  Serial.print(x162);
  Serial.print(" ");

  int x163 = bitRead(reg14, 4);
  Serial.print(x163);
  Serial.print(" ");

  int x164 = bitRead(reg14, 3);
  Serial.print(x164);
  Serial.print(" ");

  int x165 = bitRead(reg14, 2);
  Serial.print(x165);
  Serial.print(" ");

  int x166 = bitRead(reg14, 1);
  Serial.print(x166);
  Serial.print(" ");

  int x167 = bitRead(reg14, 0);
  Serial.print(x167);
  Serial.println(" ");
  
  delay(200);
}

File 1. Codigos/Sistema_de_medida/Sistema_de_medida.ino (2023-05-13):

///////// INA 3221 /////////
#include <Wire.h>                 // Inclusión de la librería para la comunicación por I2C
#include "SDL_Arduino_INA3221.h"  // Inclusión de la librería para usar el INA 3221
SDL_Arduino_INA3221 ina3221;
#define LIPO_BATTERY_CHANNEL 1    // Definición del canal 1 para la batería
#define SOLAR_CELL_CHANNEL 2      // Definición del canal 2 para el panel solar
#define OUTPUT_CHANNEL 3          // Definición del canal 3 para la carga

/////////// SD ////////////
#include <SPI.h>  // Inclusión de la librería para la comunicación por SPI
#include <SD.h>   // Inclusión de la librería para usar la SD
#define SSpin 10  // Inclusión del pin 10 para la comunicación con el esclavo
File archivo;

/////////// RTC ///////////
int seg = 0;  // Definición de la variable seg
int minu = 0; // Definición de la variable minu
int hora= 0;  // Definición de la variable hora
int dia = 0;  // Definición de la variable dia

////// Temporización //////
int periodo_ms=8000;
unsigned long t=0;

void setup(void){
  Wire.begin();
  ina3221.begin();            // Inicialización del INA 3221
  int MID;                    // Definición de la variable MID
  MID = ina3221.getManufID(); 
  SD.begin(SSpin);            // Inicialización de la comunicación con el módulo microSD
}

void loop(void){
  t=millis(); // Cálculo del tiempo que tarda en ejecutarse el codigo
  
  ///////// INA 3221 /////////
  
  archivo = SD.open("datosINA.txt", FILE_WRITE);  // Apertura para lectura/escritura del archivo datosINA.txt
  
  if (seg >= 60){ // Comprobación de si la variable seg es mayor o igual a 60
    seg -= 60;    // Resteo cada 60 segundos
    minu++;       // Suma 1 a minu
    }
  if (minu >= 60){  // Comprobación de si la variable minu es mayor o igual a 60
    minu -= 60;     // Resteo cada 60 minutos
    hora++;         // Suma 1 a hora
    }
  if (hora >= 24){  // Comprobación de si la variable hora es mayor o igual a 24
    hora -= 24;     // Resteo cada 24 horas
    dia++;          // Suma 1 a dia
    }
        
  archivo.print(dia);   // Escritura en la microSD del valor de dia
  archivo.print(" ");   // Escritura en la microSD de un espacio
  archivo.print(hora);  // Escritura en la microSD del valor de hora
  archivo.print(":");   // Escritura en la microSD de dos puntos
  archivo.print(minu);  // Escritura en la microSD del valor de minu
  archivo.print(":");   // Escritura en la microSD de dos puntos
  archivo.print(seg);   // Escritura en la microSD del valor de seg
  archivo.print(",");   // Escritura en la microSD de una coma
  archivo.print(" ");   // Escritura en la microSD de un espacio
  archivo.print(",");   // Escritura en la microSD de una coma
 
  float shuntvoltage1 = 0;  // Definición de la variable para la tensión que cae en la resistencia Shunt del canal 1
  float busvoltage1 = 0;    // Definición de la variable para la tensión que circula por el cable del canal 1
  float current_mA1 = 0;    // Definición de la variable para la corriente que circula por el cable del canal 1
  
  busvoltage1 = ina3221.getBusVoltage_V(LIPO_BATTERY_CHANNEL);      // Adquisición del valor de la tensión que circula por el cable del canal 1
  shuntvoltage1 = ina3221.getShuntVoltage_mV(LIPO_BATTERY_CHANNEL); // Adquisición del valor de la tensión que cae en la resistencia Shunt del canal 1
  current_mA1 = -ina3221.getCurrent_mA(LIPO_BATTERY_CHANNEL);       // Adquisición del valor de la corriente que circula por el cable del canal 1 
  
  archivo.print(busvoltage1);   // Escritura en la microSD del valor de la tensión en bus de la batería [V] del canal 1
  archivo.print(",");           // Escritura en la microSD de una coma
  archivo.print(shuntvoltage1); // Escritura en la microSD del valor de la tensión Shunt de la batería [mV] del canal 1
  archivo.print(",");           // Escritura en la microSD de una coma
  archivo.print(current_mA1);   // Escritura en la microSD del valor de la corriente de la batería [mA] del canal 1
  archivo.print(",");           // Escritura en la microSD de una coma
  archivo.print(" ");           // Escritura en la microSD de un espacio
  archivo.print(",");           // Escritura en la microSD de una coma
  
  float shuntvoltage2 = 0;  // Definición de la variable para la tensión que cae en la resistencia Shunt del canal 2
  float busvoltage2 = 0;    // Definición de la variable para la tensión que circula por el cable del canal 2
  float current_mA2 = 0;    // Definición de la variable para la corriente que circula por el cable del canal 2
  
  busvoltage2 = ina3221.getBusVoltage_V(SOLAR_CELL_CHANNEL);      // Adquisición del valor de la tensión que circula por el cable del canal 2
  shuntvoltage2 = ina3221.getShuntVoltage_mV(SOLAR_CELL_CHANNEL); // Adquisición del valor de la tensión que cae en la resistencia Shunt del canal 2
  current_mA2 = -ina3221.getCurrent_mA(SOLAR_CELL_CHANNEL);       // Adquisición del valor de la corriente que circula por el cable del canal 2
  
  archivo.print(busvoltage2);   // Escritura en la microSD del valor de la tensión en bus del panel solar [V] del canal 2
  archivo.print(",");           // Escritura en la microSD de una coma
  archivo.print(shuntvoltage2); // Escritura en la microSD del valor de la tensión Shunt del panel solar [mV] del canal 2
  archivo.print(",");           // Escritura en la microSD de una coma
  archivo.print(current_mA2);   // Escritura en la microSD del valor de la corriente del panel solar [mA] del canal 2
  archivo.print(",");           // Escritura en la microSD de una coma
  archivo.print(" ");           // Escritura en la microSD de un espacio
  archivo.print(",");           // Escritura en la microSD de una coma
  
  float shuntvoltage3 = 0;  // Definición de la variable para la tensión que cae en la resistencia Shunt del canal 3
  float busvoltage3 = 0;    // Definición de la variable para la tensión que circula por el cable del canal 3
  float current_mA3 = 0;    // Definición de la variable para la corriente que circula por el cable del canal 3
  
  busvoltage3 = ina3221.getBusVoltage_V(OUTPUT_CHANNEL);      // Adquisición del valor de la tensión que circula por el cable del canal 3
  shuntvoltage3 = ina3221.getShuntVoltage_mV(OUTPUT_CHANNEL); // Adquisición del valor de la tensión que cae en la resistencia Shunt del canal 3
  current_mA3 = ina3221.getCurrent_mA(OUTPUT_CHANNEL);        // Adquisición del valor de la corriente que circula por el cable del canal 3
  
  archivo.print(busvoltage3);   // Escritura en la microSD del valor de la tensión en bus de la salida [V] del canal 3
  archivo.print(",");           // Escritura en la microSD de una coma
  archivo.print(shuntvoltage3); // Escritura en la microSD del valor de la tensión Shunt de la salida [mV] del canal 3
  archivo.print(",");           // Escritura en la microSD de una coma
  archivo.println(current_mA3); // Escritura en la microSD del valor de la corriente de la salida [mA] del canal 3 y un final de línea
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
